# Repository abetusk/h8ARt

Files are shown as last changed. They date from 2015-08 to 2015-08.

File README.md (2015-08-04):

# h8ARt

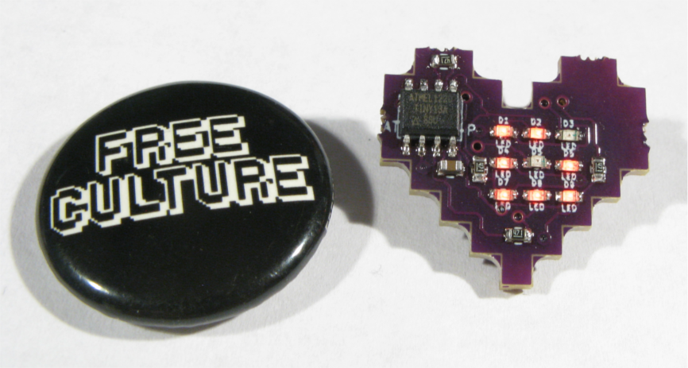
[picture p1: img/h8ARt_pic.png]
h8ARt in meatspace


Code and Gerber files for 3x3 0603 LED heart.

You can see the [project on MeowCAD](https://meowcad.com/project?projectId=12b1cb79-9d14-4319-a8cc-878b5ee93019).

All code is AGPLv3.  Everything else is under CC-BY-SA 3.0 except for qsc-8bit-3x3-2x.png which is under a CC0 license.

## Quick Start

To compile:

```bash
$ ./cmp h8ARt.asm
```

To upload (using usbtinyisp):

```bash
$ sudo ./program_avr.sh h8ARt.ihex
```

## Description

The code is written in assembly and uses an ATTiny13 to drive a 3x3 LED matrix via [Charlieplexing](https://en.wikipedia.org/wiki/Charlieplexing) (I tried writing it in C but it exhausted the 1k on the chip too quickly).

There is a message hard coded that 'scrolls' across the 3x3 LED matrix in a 'ticker tape' fashion.  Currently the message is 'OHS2015'.  The font used is a slightly modified version of [the 3x3 font from user qubodup available on OpenGameArt.org](http://opengameart.org/content/9-pixel-font-3x3).

## BOM

| Part | Count | Link |
|---|---|---|
| ATTiny13 | 1 | [Digikey](http://www.digikey.com/product-detail/en/ATTINY13A-SSUR/ATTINY13A-SSURCT-ND/3789485) |
| Red LED (0603) | 9 | Ebay |
| 470 Ohm Resistor (0603) | 4 | Ebay |
| 4.7 uF Capacitor (0603) | 1 | Ebay |
| CR1216 SMD Battery Holder | 1 | [Digikey](http://www.digikey.com/product-detail/en/BAT-HLD-012-SMT/BAT-HLD-012-SMT-ND/3044013) |
| CR1216 Battery | N | Ebay |

Boards were manufactered through [OSHPark](https://oshpark.com/).

## schematic

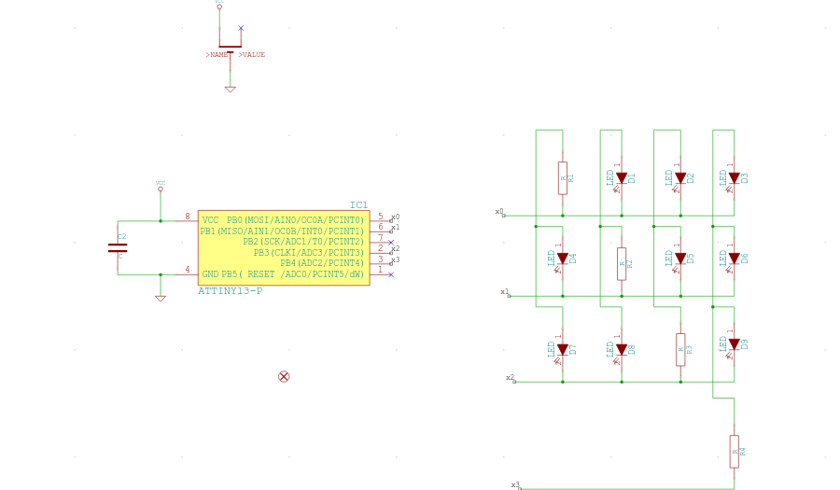
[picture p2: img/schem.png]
schem


## board

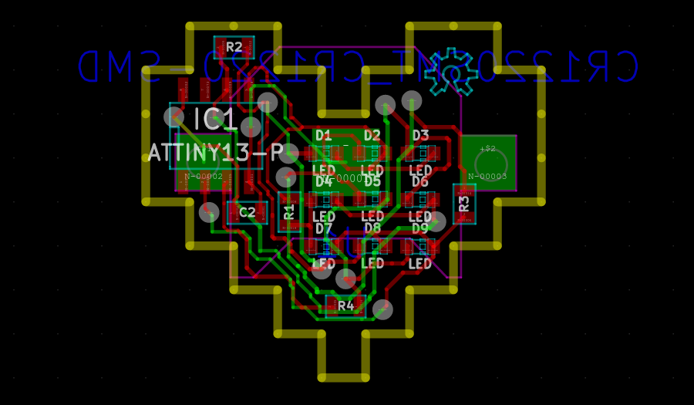
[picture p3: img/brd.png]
brd


## video

h8ARt video (http://www.youtube.com/watch?v=Gg_DkGkVkSI)

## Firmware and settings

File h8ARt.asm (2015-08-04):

;    This program is free software: you can redistribute it and/or modify
;    it under the terms of the GNU General Public License as published by
;    the Free Software Foundation, either version 3 of the License, or
;    (at your option) any later version.
;
;    This program is distributed in the hope that it will be useful,
;    but WITHOUT ANY WARRANTY; without even the implied warranty of
;    MERCHANTABILITY or FITNESS FOR A PARTICULAR PURPOSE.  See the
;    GNU General Public License for more details.
;
;    You should have received a copy of the GNU General Public License
;    along with this program.  If not, see <http://www.gnu.org/licenses/>.
;
; to compile and load:
; m4 demo.S > demo.asm
; avr-as -mmcu=attiny13 -o demo.o demo.asm
; avr-ld -o demo.elf demo.o
; avr-objcopy --output-target=ihex demo.elf demo.ihex
; avrdude -c usbtiny -p t13 -U flash:w:demo.ihex
;


.include "h8ARt_equ.S"

define(brz, breq)
define(brnz, brne)
define(bron, brne)


define(ss0l, r2)
define(ss0h, r3)

define(prev_vecl, r4)
define(prev_vech, r5)

define(state,r6)

define(zero, r8)

define(ss1l, r9)
define(ss1h, r10)


define(msg_led_state, r11)

define(aux_counter_l, r12)
define(aux_counter_h, r13)

define(back_bufl, r14)
define(back_bufh, r15)

define(msg_pause, r16)

define(tmp, r17)
define(t, r18)


define(msg_val, r19)
define(msg_prev_val, r20)

define(msg_shift, r21)

define(frame_copied, r22)

define(msg_frame, r23)

define(shift_counter, r24)

define(cur_vecl, r25)
define(cur_vech, r26)

define(bufl, r27)
define(bufh, r28)

define(zl, r30)
define(zh, r31)

.equ SREG, 0x3f
.equ TIMSK0, 0x39
.equ TCCR0B, 0x33
.equ PORTB,0x18
.equ DDRB ,0x17
.equ PINB, 0x16

;.equ MSG_PAUSE, 250
;.equ SHIFT_PAUSE, 250

.equ MSG_PAUSE, 130
.equ SHIFT_PAUSE, 70

.equ MSG_N, 7

.equ STATE_SHIFT, 0
.equ STATE_PROFILE, 1

.org 0x00
reset:
rjmp main        ; reset
rjmp defaultInt  ; ext_int0
rjmp defaultInt  ; pcint0
rjmp tim0_ovf    ; tim0_ovf
rjmp defaultInt  ; ee_rdy
rjmp defaultInt  ; ana_comp
rjmp defaultInt  ; tim0_compa
rjmp defaultInt  ; tim0_compb
rjmp defaultInt  ; watchdog
rjmp defaultInt  ; adc

defaultInt:
reti

;;;;; TIMER0 ON OVERFLOW
tim0_ovf:

  ;;;;;;;;;;;;;;
  ;;; save state
  push  tmp
  in    tmp, SREG
  push  tmp

  ;; msg_led_state = (msg_led_state+1)%9
  inc   msg_led_state
  ldi   tmp,9
  cp    msg_led_state,tmp
  brne  skip_led_state_mod
  ldi   tmp,0
  mov   msg_led_state,tmp
skip_led_state_mod:


  ;; Use a jump table to skip to the
  ;; appropriate section to charlieplex
  ;; the LEDs.
  ;; Each section checks the 'buf' variables
  ;; to see if the LED for that position
  ;; should be on.
  ;;
led_display_start:

  ldi   tmp, 0b00000000
  out   DDRB, tmp

  ldi   zh, pm_hi8(led_disp_jt)
  ldi   zl, pm_lo8(led_disp_jt)
  add   zl, msg_led_state
  adc   zh, zero
  ijmp

led_disp_jt:
  rjmp  disp_r0c0
  rjmp  disp_r0c1
  rjmp  disp_r0c2

  rjmp  disp_r1c0
  rjmp  disp_r1c1
  rjmp  disp_r1c2

  rjmp  disp_r2c0
  rjmp  disp_r2c1
  rjmp  disp_r2c2

disp_r0c0:

  sbrs  bufh,0
  rjmp  led_display_end

  ldi   tmp, 0b00000011
  out   DDRB, tmp
  ldi   tmp, 0b00000010
  out   PORTB, tmp

  rjmp  led_display_end

disp_r0c1:

  sbrs  bufl,7
  rjmp  led_display_end

  ldi   tmp, 0b00001001
  out   DDRB, tmp
  ldi   tmp, 0b00001000
  out   PORTB, tmp

  rjmp  led_display_end

disp_r0c2:

  sbrs  bufl,6
  rjmp  led_display_end

  ldi   tmp, 0b00010001
  out   DDRB, tmp
  ldi   tmp, 0b00010000
  out   PORTB, tmp

  rjmp  led_display_end

disp_r1c0:

  sbrs  bufl,5
  rjmp  led_display_end

  ldi   tmp, 0b00000011
  out   DDRB, tmp
  ldi   tmp, 0b00000001
  out   PORTB, tmp

  rjmp  led_display_end

disp_r1c1:

  sbrs  bufl,4
  rjmp  led_display_end

  ldi   tmp, 0b00001010
  out   DDRB, tmp
  ldi   tmp, 0b00001000
  out   PORTB, tmp

  rjmp  led_display_end

disp_r1c2:

  sbrs  bufl,3
  rjmp  led_display_end

  ldi   tmp, 0b00010010
  out   DDRB, tmp
  ldi   tmp, 0b00010000
  out   PORTB, tmp

  rjmp  led_display_end

disp_r2c0:

  sbrs  bufl,2
  rjmp  led_display_end

  ldi   tmp, 0b00001001
  out   DDRB, tmp
  ldi   tmp, 0b00000001
  out   PORTB, tmp

  rjmp  led_display_end

disp_r2c1:

  sbrs  bufl,1
  rjmp  led_display_end

  ldi   tmp, 0b00001010
  out   DDRB, tmp
  ldi   tmp, 0b00000010
  out   PORTB, tmp

  rjmp  led_display_end

disp_r2c2:

  ldi   frame_copied, 1

  sbrs  bufl,0
  rjmp  led_display_end

  ldi   tmp, 0b00011000
  out   DDRB, tmp
  ldi   tmp, 0b00010000
  out   PORTB, tmp

  rjmp  led_display_end

led_display_end:

tim0_end:

    pop   tmp
    out   SREG, tmp
    pop   tmp

reti



;;;;;;;;;;;;
;;;;
;;;; MAIN 
;;;;
;;;;;;;;;;;;
main:


  ;;;;;;;;;;;;;;;;
  ;;;;;; init

  ; All PB disabled initially
  ldi   tmp, 0x00
  out   DDRB, tmp

  ; no prescaling
  in    tmp, TCCR0B
  andi  tmp, 0xf8
  ori   tmp, 1
  out   TCCR0B, tmp

  ; enable timer interrupte
  in    tmp, TIMSK0
  ori   tmp, 2
  out   TIMSK0, tmp

  ; initialize global variables
  eor   zero, zero

  eor   frame_copied, frame_copied
  eor   bufl, bufl
  eor   bufh, bufh
  eor   msg_led_state,msg_led_state

  eor   back_bufl, back_bufl
  eor   back_bufh, back_bufh

  eor   msg_shift, msg_shift
  eor   msg_frame,msg_frame

  eor   t, t
  eor   tmp, tmp

  ;;DEBUG
  ldi   bufh, 0b00000001
  ldi   bufl, 0b01111010
  mov   back_bufh,bufh
  mov   back_bufl,bufl

  mov   cur_vecl,bufl
  mov   cur_vech,bufh
  mov   prev_vecl,cur_vecl
  mov   prev_vech,cur_vech
  ldi   shift_counter,SHIFT_PAUSE

  ; <3
  ldi   tmp,0b00000001
  mov   prev_vecl,tmp
  ldi   tmp,0b01111010
  mov   prev_vech,tmp

  ; 'k'
  ;ldi   cur_vech, 0b00000001
  ;ldi   cur_vecl, 0b01110101

  ldi   cur_vech, 0b00000001
  ldi   cur_vecl, 0b10101111


  ;;DEBUG


  eor   aux_counter_l, aux_counter_l
  eor   frame_copied,frame_copied
  eor   msg_val,msg_val

  eor   msg_frame,msg_frame
  eor   msg_pause,msg_pause

  sei

;;----------------------------------------------------
;;                  _                  _     _ _
;;  _ __ ___   __ _(_)_ __   __      _| |__ (_) | ___ 
;; | '_ ` _ \ / _` | | '_ \  \ \ /\ / / '_ \| | |/ _ \
;; | | | | | | (_| | | | | |  \ V  V /| | | | | |  __/
;; |_| |_| |_|\__,_|_|_| |_|___\_/\_/ |_| |_|_|_|\___|
;;                        |_____|                     
;;----------------------------------------------------
;;
main_while:

  ;; trigger on frame update
  ;;
  tst   frame_copied
  brz   main_while
  eor   frame_copied, frame_copied

  ;; load screen with back buffer
  ;;
  cli
  mov   bufh,back_bufh
  mov   bufl,back_bufl
  sei

  ;;DEBUG
  ;ldi   t,STATE_PROFILE
  ;ldi   t,STATE_SHIFT
  ;mov   state, t

  ;ldi   tmp,0b10101010
  ;mov   prev_vecl,tmp
  ;ldi   tmp,0b00000000
  ;mov   prev_vech,tmp
  ;ldi   cur_vecl,0b01010101
  ;ldi   cur_vech,0b00000001
  ;ldi   msg_shift,0
  ;ldi   shift_counter,10
  ;ldi   shift_counter,SHIFT_PAUSE
  ;;DEBUG


  ;; state test
  ;;
  mov   t,state
  cpi   t,STATE_SHIFT
  breq  state_shift

  rjmp  state_message_profile
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

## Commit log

2015-08-04 adding json and gerber files
    [board-B_Cu.gbl, board-B_SilkS.gbo, board-B_SolderM.gbs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]
2015-08-04 Description and BOM
2015-08-04 screenshot of assembled circuit
